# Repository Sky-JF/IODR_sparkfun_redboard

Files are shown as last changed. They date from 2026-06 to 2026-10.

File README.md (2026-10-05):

# IODR_sparkfun_redboard

Second iteration of the IODR Device for the Olson Lab. The current project uses a Sparkfun IoT Redboard ESP32 Development Board and more advanced and higher accuracy sensors, such as the as726x and veml6030 produced by Sparkfun. 

The IODR collects optical density/absorbance data of samples in test tubes and uploads them to a locally run database that can be accessed by the IODR frontend server. The frontend data viewing interface is hosted on Heroku and was developed by another previous undergraduate in the Olson lab, Raif Olson. Find related links in the Additional Projects section.

This project also features other programs that can be used to test the accuracy of the sensors used in the IODR. All of the programs in this repository are mainly coded in micropython. Some powershell scripts are provided for automating certain interactions with the development board.

## Navigation
This repository features three main programs for the development board:
- `./CLI_controller/`

  This program provides a CLI to manually control the IODR. The controller allows for selection and configuration of different sensors (veml6030, temt6000, as726x), measuring of optical density or sensor light values, automatic data collection of all sensor configurations, as well as saving data to download onto a computer. 
  This program contains 2 scripts to download data collected while using the CLI:
  - `retreive_data.ps1`
    
    Retreives data collected manually
  - `retreive_full_settings_test.ps1`

    Retreives data collected from the test for all settings for both the veml6030 and the as726x sensors
- `./single_sensor_IODR/`

  This program functions like the Arduino Giga IODR, collecting data and sending it to the database, but with only one sensor. 
- `./multi_sensor_IODR/`

  This program implements reading of multiple sensors, similar to the Arduino Giga IODR.

Note: `./singe_sensor_IODR/` and `./multi_sensor_IODR/` both contain a file `secrets.py` which should be included in the `./lib` folder and which should contain sensitive information that is uploaded to the board. To create one of these files locally, use the `secrets_template.py`, fill in its variables, and rename it to `secrets.py`. 

Additionally, several tests for different modules of each main program is included in `./module_tests`. To run these tests, simply upload the files and observe their serial output.

The folder `./Physical_parts` contains the files used to 3D print the physical parts used in this project. 

## Setup
Before uploading any programs to the Sparkfun development board, make sure the correct micropython firmware is uploaded first.
1. Download the [SparkFun MicroPython Firmware Uploader](https://github.com/sparkfun/SparkFun_MicroPython_Firmware_Uploader) 
2. Press the boot button on the development board
3. Select the serial port connected to the development board
4. Choose the `ESP32_GENERIC-20251209-v1.27.0.bin` firmware file
5. Flash the firmware
6. Reboot the board

## How to use
This repository features two types of powershell scripts for Windows which are used to interact with the development board:
- `upload.ps1`
  This script uploads each python file to the development board in order to program it. There is a specific `upload.ps1` that uploads all necessary files for each of the main programs. 
  - To upload a local file to the development board, use the command `mpremote.exe fs cp <local_file_path> :<microprocessor_file_path>` (e.g. `mpremote.exe fs cp ./lib/wifi.py :/lib/`).
  - To upload a file from github, use the command `mpremote.exe mip install github:<github_user>/<github_repository>` (e.g. `mpremote.exe mip install github:sparkfun/qwiic_veml6030_py`). Before uploading this file, make sure it is installed through pip.
- `connect.ps1`
  This script establishes serial communication with the boards and functions as a serial output/input for the program that is currently running on the development board. The shell used to run the script becomes the serial print line for the development board. 

## Dependencies
- `mpremote` This package allows for executing some commands in the microcontroller as if it were a shell. This package is mainly used for uploading files to the development board and to establish serial communication.
- `sparkfun_qwiic_as726x` This package includes the library used to interface with the as726x sensor through I2C.
- `sparkfun_qwiic_i2c` This package includes the dependencies needed to use the I2C interface that is provided by Sparkfun.
- `sparkfun_qwiic_veml6030` This package includes the library used to interface with the veml6030 sensor through I2C.

### How to install (Windows)
1. Make sure python and pip are installed in your computer
2. Activate python virtual environment
  ```
  py -m venv .venv
  .\.venv\Scripts\activate
  ```
3. Install dependencies
  ```
  pip install mpremote
  pip install sparkfun-qwiic-as726x
  pip install sparkfun-qwiic-i2c
  pip install sparkfun-qwiic-veml6030
  ```

### Other useful dependencies
- esptool 
  Used for uploading firmware to esp32 boards. To update the firmware in a (ESP32) board, download the firmware of the board being used [here](https://micropython.org/download/SPARKFUN_IOT_REDBOARD_ESP32/) and use the following commands (in windows):
  ```
    esptool --port <USB port address> erase-flash
    esptool --port <USB port address> write-flash 0x1000 <path to binary file>
  ```

## Hardware used in this project
- SparkFun IoT Redboard Development Board
- SparkFun Ambient Light Sensor - VEML6030 (Qwiic)
- SparkFun Ambient Light Sensor Breakout - TEMT6000
- SparkFun Spectral Sensor Breakout - AS726x Visible (Qwiic)

## Resources
- [Sparkfun IoT Redboard ESP32 Development Board main page](https://www.sparkfun.com/sparkfun-iot-redboard-esp32-development-board.html)
- [Sparkfun ESP32 data sheet](https://cdn.sparkfun.com/datasheets/IoT/esp32_datasheet_en.pdf)

## Additional Projects
- [Frontend data viewer](https://iodr-605db139538a.herokuapp.com)
- [GitHub repository for frontend data viewer](https://github.com/danolson1/IODR_project?tab=readme-ov-file#readme)
- [Thingspeak data webpage](https://thingspeak.mathworks.com/channels/469909)
- [Arduino Giga IODR repository](https://github.com/Sky-JF/IODR_Device)

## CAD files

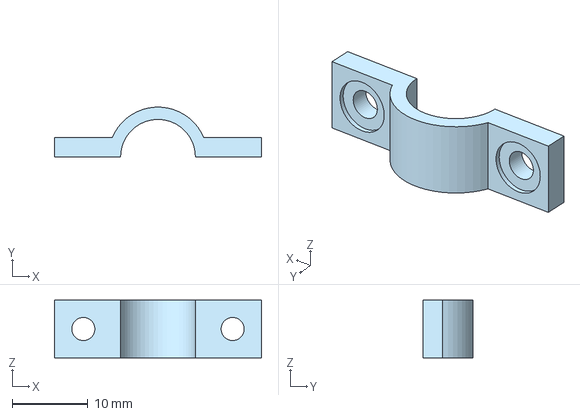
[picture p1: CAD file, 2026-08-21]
Physical_parts/IODR cable clips.step
27.3 x 6.55 x 7.62 mm

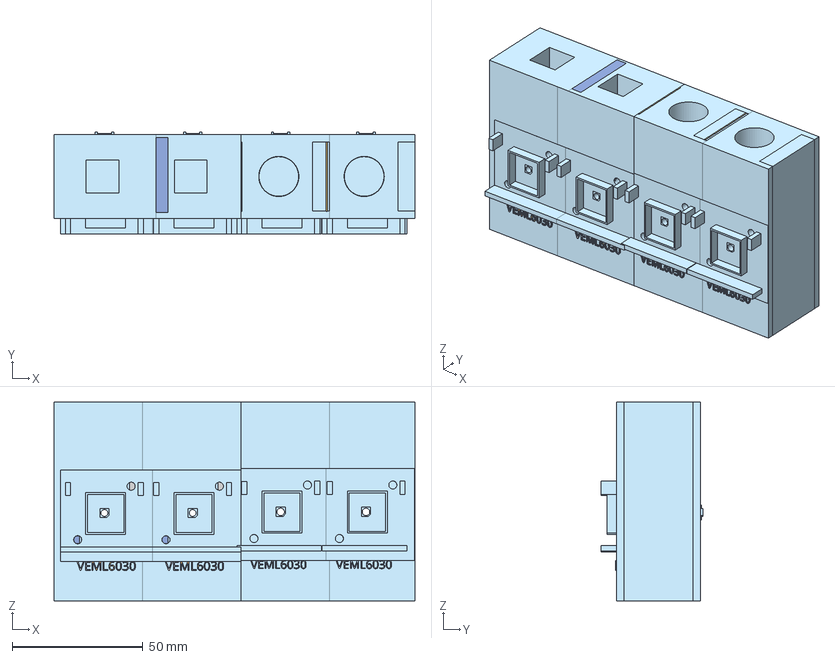
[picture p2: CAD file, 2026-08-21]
Physical_parts/IODR VEML6030 block v2.step
137.9 x 39.0 x 76.0 mm

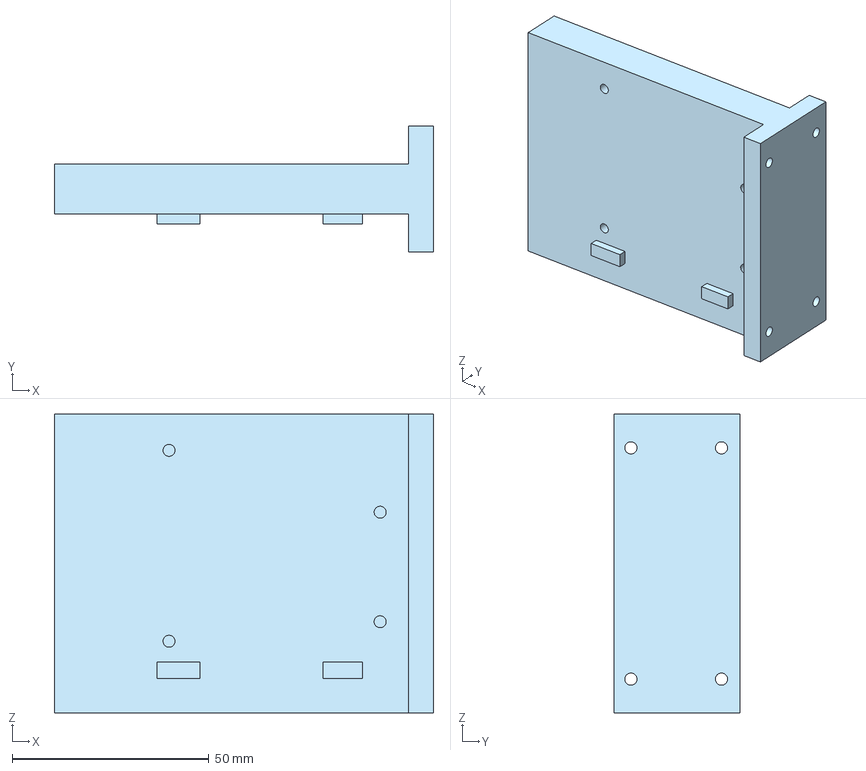
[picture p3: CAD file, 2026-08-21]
Physical_parts/IODR extension v2.step
96.4 x 32.0 x 76.0 mm

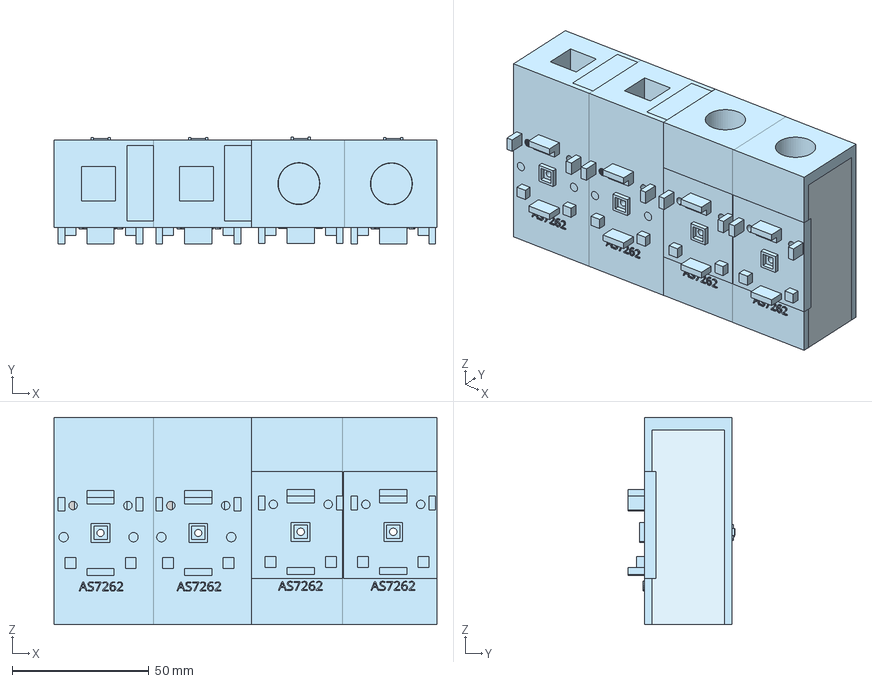
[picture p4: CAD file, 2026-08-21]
Physical_parts/IODR AS7262 block v3.step
140.3 x 39.1 x 76.0 mm

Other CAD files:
Physical_parts/IODR AS7262 block v3.stl
Physical_parts/IODR VEML6030 block v2.stl
Physical_parts/IODR cable clips.stl
Physical_parts/IODR extension v2.stl

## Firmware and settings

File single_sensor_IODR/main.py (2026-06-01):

"""
main.py
-------
Continuous optical density data collection loop.
MicroPython port of the Arduino IODR project.

Architecture
------------
- Reads light sensors at a fast interval (OD_READ_INTERVAL_MS)
- Averages readings over POINTS_TO_AVERAGE samples
- Uploads averaged OD + temperature data to InfluxDB every UPLOAD_INTERVAL_MS

Hardware assumptions
--------------------
- LED controlled by a single transistor on pin 17 (shared across all tubes)
- VEML6030 sensors wired to separate I2C buses, or a single sensor for testing
- AS726x sensor on I2C bus 0 (SCL=22, SDA=21)
- Temperature: onboard or external sensor (replace get_temperature() as needed)

To add more tubes
-----------------
- VEML6030:  instantiate more QwiicVEML6030 objects and add them to VEML_SENSORS
- AS726x:    instantiate more QwiicAS726x objects and add them to AS726X_SENSORS
Tube numbers are 1-indexed in InfluxDB (matching Arduino convention).
"""

import machine
import time
import sys

import sensors as sens
import config_routine
import wifi
from influxdb_lib import InfluxDBClient
from secrets import INFLUX_DB_API_TOKEN

# ---------------------------------------------------------------------------
# Configuration
# ---------------------------------------------------------------------------

DEVICE_ID           = 1          # IODR device number (written to every InfluxDB point)
UPLOAD_INTERVAL_MS  = 90_000     # how often to push data to InfluxDB (90 s, matches Arduino)
OD_READ_INTERVAL_MS = 800        # how often to take a light reading (matches Arduino)
POINTS_TO_AVERAGE   = 10         # readings averaged before upload (matches Arduino)

# Which sensor type is active: "veml6030" | "as726x"
ACTIVE_SENSOR = "as726x"

# InfluxDB connection — edit to match your server
INFLUXDB_HOST   = "olsonlab-iodr.kiewit.dartmouth.edu"
INFLUXDB_PORT   = 8086
INFLUXDB_TOKEN  = INFLUX_DB_API_TOKEN
INFLUXDB_ORG    = "olsonlab"
INFLUXDB_BUCKET = "iodr_test"

# ---------------------------------------------------------------------------
# Hardware setup
# ---------------------------------------------------------------------------

# Shared LED transistor pin (controls all LEDs across all tubes)
led = machine.Pin(17, machine.Pin.OUT)

# Blank button — pin A5, active high (reads 1 when pressed)
# Only checked when ACTIVE_SENSOR == "as726x"
blank_button = machine.Pin(33, machine.Pin.IN, machine.Pin.PULL_UP)  # A5 on ESP32 is GPIO33

# I2C bus for sensors
i2c0 = machine.I2C(0, scl=machine.Pin(22), sda=machine.Pin(21), freq=400_000)

# ---------------------------------------------------------------------------
# Multi-tube sensor lists
# ---------------------------------------------------------------------------
# Add one sensor object per test tube.
# If you only have one sensor, leave a single-element list.
# For multiple VEML6030s on different I2C buses, create separate I2C objects:
#   i2c1 = machine.I2C(1, scl=machine.Pin(xx), sda=machine.Pin(yy), freq=400_000)
#   veml2 = qwiic_veml6030.QwiicVEML6030(i2c=i2c1)

import qwiic_veml6030
import qwiic_as726x

VEML_SENSORS   = [
    qwiic_veml6030.QwiicVEML6030(),   # Tube 1
    # qwiic_veml6030.QwiicVEML6030(i2c=i2c1),  # Tube 2 – add more buses as needed
]

AS726X_SENSORS = [
    qwiic_as726x.QwiicAS726x(i2c0),  # Tube 1
    # qwiic_as726x.QwiicAS726x(i2c1),  # Tube 2
]

# configs dict mirrors the original main.py structure
# wind_up_time / wind_down_time start at 0.5 s.
# For the AS726x, setup() runs config_routine which overwrites these with
# values derived from the ideal integration time found by binary search.
configs = {
    "sensor":         ACTIVE_SENSOR,
    "blank":          None,
    "blank_set":      False,
    "data":           [],
    "wind_up_time":   0.5,   # updated by config_routine for AS726x
    "wind_down_time": 0.5,   # updated by config_routine for AS726x
}

# ---------------------------------------------------------------------------
# InfluxDB client
# ---------------------------------------------------------------------------
db = InfluxDBClient(
    host   = INFLUXDB_HOST,
    port   = INFLUXDB_PORT,
    token  = INFLUXDB_TOKEN,
    org    = INFLUXDB_ORG,
    bucket = INFLUXDB_BUCKET,
)

# ---------------------------------------------------------------------------
# Blank values — one per tube (mirrors Arduino's blankValue[] array)
# ---------------------------------------------------------------------------
blank_values = [None] * max(len(VEML_SENSORS), len(AS726X_SENSORS), 1)

# ---------------------------------------------------------------------------
# Timing state (mirrors Arduino's millis() pattern)
# ---------------------------------------------------------------------------
last_od_read_time    = time.ticks_ms()
last_upload_time     = time.ticks_ms()
accumulated_readings = []   # list of per-cycle results, averaged before upload

# ---------------------------------------------------------------------------
# Temperature helper
# ---------------------------------------------------------------------------

def get_temperature():
    """
    Placeholder — replace with your actual temperature sensor code.
    Returns None if no sensor is available.
    """
    # Example using a DS18x20 on a OneWire bus (install micropython-onewire):
    # import onewire, ds18x20
    # ow  = onewire.OneWire(machine.Pin(8))
    # ds  = ds18x20.DS18X20(ow)
    # roms = ds.scan()
    # if roms:
    #     ds.convert_temp()
    #     time.sleep_ms(750)
    #     return ds.read_temp(roms[0])
    return None


# ---------------------------------------------------------------------------
# Blank calibration
# ---------------------------------------------------------------------------

def set_blank():
    """
    Measure blank values for all tubes using the active sensor type.
    Called once before OD collection begins.
    """
    global blank_values, configs

    print("Setting blank values for sensor:", ACTIVE_SENSOR)

    if ACTIVE_SENSOR == "veml6030":
        light_in = sens.read_all_veml6030(
            VEML_SENSORS, led, configs, POINTS_TO_AVERAGE
        )
        blank_values = light_in
        configs["blank"]     = light_in
        configs["blank_set"] = True

    elif ACTIVE_SENSOR == "as726x":
        light_in = sens.read_all_as726x(
            AS726X_SENSORS, led, configs, POINTS_TO_AVERAGE
        )
        blank_values = light_in
        configs["blank"]     = light_in[0] if light_in else None
        configs["blank_set"] = True

    print("Blank set:", blank_values)


# ---------------------------------------------------------------------------
# OD reading
# ---------------------------------------------------------------------------

def read_od_all_tubes():
    """
    Read all tubes for the active sensor type.

    Returns
    -------
    list of (tube_number, od_float) — tube numbers are 1-indexed.
    """
    results = []

    if ACTIVE_SENSOR == "veml6030":
        light_in = sens.read_all_veml6030(
            VEML_SENSORS, led, configs, POINTS_TO_AVERAGE
        )
        for i, val in enumerate(light_in):
            blank = blank_values[i] if i < len(blank_values) else 1.0
            blank = blank if blank is not None else val
            od    = sens.compute_od(val, blank)
            results.append((i + 1, od))

    elif ACTIVE_SENSOR == "as726x":
        light_in = sens.read_all_as726x(
            AS726X_SENSORS, led, configs, POINTS_TO_AVERAGE
        )
        for i, val in enumerate(light_in):
            blank = blank_values[i] if i < len(blank_values) else 1.0
            blank = blank if blank is not None else val
            od    = sens.compute_od(val, blank)
            results.append((i + 1, od))

    return results


# ---------------------------------------------------------------------------
# Upload
# ---------------------------------------------------------------------------

def upload_to_influxdb(od_results):
    """
    Upload the averaged OD results and current temperature to InfluxDB.

    Parameters
    ----------
    od_results : list – output of read_od_all_tubes(), always
                 [(tube_number, od_float), ...] regardless of sensor type
    """
    wifi.reconnect_if_needed()   # guard against link loss between upload cycles
    print("Uploading to InfluxDB...")
    db.write_od_data(DEVICE_ID, od_results)

    temp = get_temperature()
    if temp is not None:
        db.write_temperature(DEVICE_ID, temp)
        print("Temperature uploaded: {:.2f} °C".format(temp))
    else:
        print("No temperature sensor found, skipping temperature upload.")


# ---------------------------------------------------------------------------
# Setup
# ---------------------------------------------------------------------------

def setup():
    print("IODR MicroPython — starting up")
    print("Active sensor:", ACTIVE_SENSOR)
    print("Device ID:", DEVICE_ID)

    # Connect to WiFi before anything else — urequests needs an active link
    wifi.connect()
    if ACTIVE_SENSOR == "veml6030":
        for i, veml in enumerate(VEML_SENSORS):
            ok = veml.begin()
            if not ok:
                print("VEML6030 tube {} not found. Check wiring.".format(i + 1))
            else:
                veml.set_gain(0.125)
                veml.set_integ_time(100.0)
                print("VEML6030 tube {} initialised.".format(i + 1))

    elif ACTIVE_SENSOR == "as726x":
        for i, sensor in enumerate(AS726X_SENSORS):
            if not sensor.is_connected():
                print("AS726x tube {} not connected.".format(i + 1))
            elif not sensor.begin():
                print("AS726x tube {} failed to begin.".format(i + 1))
            else:
                sensor.set_gain(2)
                print("AS726x tube {} initialised.".format(i + 1))

        print("\nRunning AS726x integration-time calibration (orange channel)...")
        config_routine.find_ideal_integration_time(configs, led)
        print("Calibration complete. wind_up={:.4f}s  wind_down={:.4f}s".format(
            configs["wind_up_time"], configs["wind_down_time"]
        ))

    # Set blank
    print("\nSetting blank values — ensure tube holders are filled with blank solution.")
    set_blank()
    print("Blank set. Starting continuous data collection.\n")


# ---------------------------------------------------------------------------
# Main loop
# ---------------------------------------------------------------------------

def loop():
    """
    Continuous data collection loop — mirrors the Arduino loop() function.

    Reads OD at OD_READ_INTERVAL_MS and uploads averaged data
    to InfluxDB every UPLOAD_INTERVAL_MS.

    For the AS726x only: if the blank button (pin A5) is held high,
    re-runs set_blank() and clears the accumulated readings buffer so
    the next upload only contains post-blank data.
    """
    global last_od_read_time, last_upload_time, accumulated_readings

    # --- Blank button check (AS726x only) ---
    if ACTIVE_SENSOR == "as726x" and blank_button.value() == 0:
        print("Blank button pressed — re-calibrating...")
        # Integration time
        print("\nRunning AS726x integration-time calibration (orange channel)...")
        config_routine.find_ideal_integration_time(configs, led)
        print("Calibration complete. wind_up={:.4f}s  wind_down={:.4f}s".format(
            configs["wind_up_time"], configs["wind_down_time"]
        ))

        # Blank values
        set_blank()
        accumulated_readings = []  # discard readings taken before the new blank
        print("Re-blank complete. Resuming data collection.")
        # Wait for the button to be released before continuing
        while blank_button.value() == 0 and False: # Currently disabled because of hardware issues with button
            time.sleep_ms(50)

    # --- OD read cycle ---
    now = time.ticks_ms()
    if time.ticks_diff(now, last_od_read_time) >= OD_READ_INTERVAL_MS:
        od_results = read_od_all_tubes()

        # Print current readings to REPL
        for tube_num, od_val in od_results:
            print("Tube {}: OD = {:.4f}".format(tube_num, od_val))

        accumulated_readings.append(od_results)
        last_od_read_time = time.ticks_ms()

    # --- Upload cycle ---
    if time.ticks_diff(time.ticks_ms(), last_upload_time) >= UPLOAD_INTERVAL_MS:
        if accumulated_readings:
            # Average the OD readings collected since the last upload
            averaged = average_od_readings(accumulated_readings)
            upload_to_influxdb(averaged)
            accumulated_readings = []   # clear the buffer
        last_upload_time = time.ticks_ms()

    # Small sleep to avoid busy-waiting
    time.sleep_ms(50)


def average_od_readings(reading_list):
    """
    Average a list of OD reading sets.

    Parameters
    ----------
    reading_list : list of list – each inner list is one cycle's output of
                   read_od_all_tubes(), i.e. [(tube_num, od_float), ...]

    Returns
    -------
    list of (tube_num, averaged_od_float)
    """
    if not reading_list:
        return []

    num_tubes = len(reading_list[0])
    result    = []

    for t in range(num_tubes):
        tube_num = reading_list[0][t][0]
        valid    = [r[t][1] for r in reading_list if r[t][1] >= 0]
        avg      = sum(valid) / len(valid) if valid else -1.0
        result.append((tube_num, avg))

    return result


# ---------------------------------------------------------------------------
# Entry point
# ---------------------------------------------------------------------------

if __name__ == "__main__":
    setup()
    try:
        while True:
            loop()
    except (KeyboardInterrupt, SystemExit):
        print("\nStopping data collection.")
        led.value(led_OFF)
        sys.exit(0)

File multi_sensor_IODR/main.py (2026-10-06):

"""
main.py — MUX-enabled, 3-sensor parallel version.

Uses a SparkFun Qwiic I2C MUX (TCA9548A) to address all sensors that share
a single I2C bus. All LEDs are wired in parallel, with their light up order
determined by the functions in led_ctrl.py. MUX channels are quickly cycled
to read each sensor before turning the LED off again.
"""

import machine
import time
import sys

import sensors as sens
import config_routine
import wifi
import led_ctrl          # NeoPixel / builtin LED setup 
from influxdb_lib import InfluxDBClient

import qwiic_veml6030
import qwiic_as726x
import qwiic_tca9548a          # SparkFun Qwiic MUX driver

# ---------------------------------------------------------------------------
# Config
# ---------------------------------------------------------------------------
# All hardware/deployment constants (including the InfluxDB token from
# secrets.py) now live in manual_config.py.
from manual_config import (
    DEVICE_ID, UPLOAD_INTERVAL_MS, OD_READ_INTERVAL_MS, POINTS_TO_AVERAGE,
    MUX_CHANNELS, ACTIVE_SENSOR,
    VEML6030_GAIN, VEML6030_INTEG_TIME_MS, AS726X_GAIN_CODE,
    SEQUENTIAL_LEDS, 
    INFLUXDB_HOST, INFLUXDB_PORT, INFLUXDB_TOKEN, INFLUXDB_ORG, INFLUXDB_BUCKET,
    I2C_BUS_ID, I2C_SCL_PIN, I2C_SDA_PIN, I2C_FREQ_HZ,
    BLANK_BUTTON_PIN,
)

# ---------------------------------------------------------------------------
# Hardware setup
# ---------------------------------------------------------------------------
i2c0 = machine.I2C(I2C_BUS_ID, scl=machine.Pin(I2C_SCL_PIN),
                   sda=machine.Pin(I2C_SDA_PIN), freq=I2C_FREQ_HZ)  

# Let SparkFun's qwiic_i2c layer create the wrapped driver — its chip
# drivers expect writeCommand()/readBlock(), not raw machine.I2C methods.
mux = qwiic_tca9548a.QwiicTCA9548A()
if not mux.is_connected():
    print("ERROR: Qwiic MUX not found at 0x70. Check wiring.")
    sys.exit(1)
print("Qwiic MUX detected.")


# ---------------------------------------------------------------------------
# MUX-aware sensor proxy
# ---------------------------------------------------------------------------
# Wraps a sensor object so that every attribute access first enables the
# correct MUX channel. This keeps sensors.py unchanged [4] — the wrapped
# objects behave exactly like the underlying QwiicVEML6030 / QwiicAS726x.
class MuxedSensor:
    def __init__(self, mux, channel, sensor):
        self._mux     = mux
        self._channel = channel
        self._sensor  = sensor

    def _select(self):
        # Disable all channels then enable just this one — guarantees only
        # one device is on the bus at a time.
        self._mux.disable_all()
        self._mux.enable_channels(self._channel)

    def __getattr__(self, name):
        attr = getattr(self._sensor, name)
        if callable(attr):
            def wrapped(*args, **kwargs):
                self._select()
                return attr(*args, **kwargs)
            return wrapped
        # Non-callable attribute — still need the right channel selected
        self._select()
        return attr


# ---------------------------------------------------------------------------
# Build sensor lists — one entry per MUX channel
# ---------------------------------------------------------------------------
def _make_veml_for_channel(ch):
    mux.disable_all()
    mux.enable_channels(ch)
    return MuxedSensor(mux, ch, qwiic_veml6030.QwiicVEML6030())

def _make_as726x_for_channel(ch):
    mux.disable_all()
    mux.enable_channels(ch)
    return MuxedSensor(mux, ch, qwiic_as726x.QwiicAS726x())   # no i2c arg

if ACTIVE_SENSOR == "veml6030":
    VEML_SENSORS   = [_make_veml_for_channel(ch) for ch in MUX_CHANNELS]
    AS726X_SENSORS = []
else:
    VEML_SENSORS   = []
    AS726X_SENSORS = [_make_as726x_for_channel(ch) for ch in MUX_CHANNELS]


# ---------------------------------------------------------------------------
# Shared configs dict (used by sensors.py and config_routine.py) [1][2]
# ---------------------------------------------------------------------------
configs = {
    "sensor":         ACTIVE_SENSOR,
    "blank":          None,
    "blank_set":      False,
    "data":           [],
    "wind_up_time":   0.5,
    "wind_down_time": 0.5,
}

blank_values = [None] * len(MUX_CHANNELS)

# ---------------------------------------------------------------------------
# InfluxDB client [3]
# ---------------------------------------------------------------------------
db = InfluxDBClient(
    host   = INFLUXDB_HOST,
    port   = INFLUXDB_PORT,
    token  = INFLUXDB_TOKEN,
    org    = INFLUXDB_ORG,
    bucket = INFLUXDB_BUCKET,
)


# ---------------------------------------------------------------------------
# Temperature helper (unchanged) [1]
# ---------------------------------------------------------------------------
def get_temperature():
    return None

# ---------------------------------------------------------------------------
# Fast multi-sensor read — single LED pulse, multiple reads
# ---------------------------------------------------------------------------
# Because the LEDs are wired in parallel, one LED-on event lights every tube
# simultaneously. We read all channels inside one wind_up / wind_down
# window — the channel switch is microseconds compared to the millisecond-
# scale integration time of the sensors.
def _read_all_channels_one_shot():
    """
    Performs one ambient + one signal read across all MUX channels using
    a single shared LED pulse. Returns ambient-subtracted readings, one
    per channel, in the same order as MUX_CHANNELS.
    """
    sensor_list = AS726X_SENSORS if ACTIVE_SENSOR == "as726x" else VEML_SENSORS

    # --- ambient (LED off) ---
    led_ctrl.set_tube_leds(led_ctrl.LED_OFF)    
    led_ctrl.set_builtin_led(led_ctrl.LED_OFF)  
    time.sleep(configs["wind_up_time"])
    ambient = []
    for s in sensor_list:
        if ACTIVE_SENSOR == "as726x":
            s.take_measurements()
            ambient.append(s.get_calibrated_orange())
        else:
            ambient.append(float(s.read_light()))

    # --- signal (LED on) ---
    led_ctrl.set_tube_leds(led_ctrl.LED_ON)    
    led_ctrl.set_builtin_led(led_ctrl.LED_ON)  
    time.sleep(configs["wind_up_time"])
    signal = []
    for s in sensor_list:
        if ACTIVE_SENSOR == "as726x":
            s.take_measurements()
            signal.append(s.get_calibrated_orange())
        else:
            signal.append(float(s.read_light()))

    led_ctrl.set_tube_leds(led_ctrl.LED_OFF)    
    led_ctrl.set_builtin_led(led_ctrl.LED_OFF)  
    time.sleep(configs["wind_down_time"])

    # +0.1 to avoid log(0) downstream, matching sensors.py behaviour [4]
    return [signal[i] - ambient[i] + 0.1 for i in range(len(sensor_list))]
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

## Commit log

2026-01-14 Revert "Added files"
    This reverts commit e2be5ea362bcd21c94d3396ad7cd7cc88a2e9331.
    [main.py]
2026-01-14 Fixed minor bugs with cli
    [main.py]
2026-02-05 Added file saving and multiple reads for as726x and configs for i2x sensors
2026-03-23 Improved modularization. Fixed light reading offset
    [main.py]
2026-06-01 Finalized implementation of multiple sensors and added better README descriptions
2026-08-21 Added Tilda's files for 3D printing
    [IODR AS7262 block v3.step, IODR AS7262 block v3.stl, IODR VEML6030 block v2.step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]
2026-09-28 Progress on implementing reading for both sensor types
2026-09-28 Integrated neopixel led use
2026-10-05 Refactored led use and added manual config file
2026-10-05 Implemented led cycling so only 1 lights up
